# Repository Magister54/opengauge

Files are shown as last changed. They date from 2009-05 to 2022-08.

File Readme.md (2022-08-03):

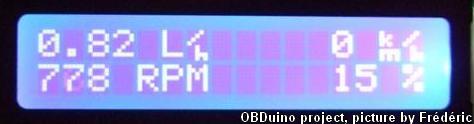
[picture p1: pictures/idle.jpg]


# Introduction #

The OBDuino is an in-car real-time display of various information, like speed, RPM, instant fuel consumption or average trip fuel consumption as well as others PIDs supported by the car.

# Details #

The name OBDuino comes from OBD which means [On Board Diagnostics](http://en.wikipedia.org/wiki/On_Board_Diagnostics) and from the development board which is an [Arduino](http://arduino.cc) (or a clone).
_Technical info_: It is based on an Atmel AVR ATMEGA168P chip that contains 16K of flash, 1K of RAM and 512bytes of EEPROM, an LCD display, 3 buttons, a few $ of electronics components.

The OBDuino connects to the car on its OBD-II plug which is, in general, under the dash. A lot of signals are on this plug as well as battery voltage and ground. Using a standard OBD-II to DB9F cable brings us what we need.

The [interface](OBDuinoInterface.md) to the car is made with either a Freescale MC33290 for ISO only, a Microchip 2515 for CAN only, or an ELM327 (a third-party pre-programmed PIC) that talks PWM/VPW/ISO/CAN but it is more expensive and can require more hardware work if you want to use all protocols.

OBDuino can display 4 informations at a time, and there is virtual screens to have access to others PIDs. By default there is 3 screens available so it makes 12 PIDs available quickly.

# Main Hardware #

The Arduino or a clone can be purchased assembled, in a kit, or you can even etch it yourself. Take the flavour you want for serial or USB depending on your PC/laptop configuration (you need the port to program the chip). All the clone should work the same, except the very small one that use 3.3V and 8MHz and even there, it should work too with some adaptation. It costs about $15-$33 depending of your choice.

To play with, you can start with a "big" board like an Arduino Diecimila or a Freeduino SB, and to integrate in the car you can use a Boarduino or an iDuino by after.

The LCD screen used is a 2 rows x 16 characters using a standard HD44780 or compatible chipset, they can be found on eBay for $4, and they exist in almost every colours as well as STN, FSTN and even OLED (although more expensive).

The 3 buttons are momentary push button switches, take the one you want. You also need a 220 ohms resistor and a PNP 2N3906 transistor or equivalent like an NTE159 to drive the LCD brightness, as it can take up to 200mA on some LCD and the pin used to drive brightness is limited to about 20mA. radio-shack has them, or online electronic parts seller like Digikey or Mouser.

With this you have the main hardware and now need the car interface.

# Interfaces #

The code can use multiple interface (although one at a time), you will need to make the interface specific for your car, see [Interface](OBDuinoInterface.md). If your car is sold in north-america and is a 2008+ it uses CAN so you can built the interface using Microchip MCP2515 and MCP2551.

Interface connect to the Arduino on a few pins, depending on your choice, the LCD will be connected differently, see [Diagram](OBDuinoDiagram.md).

# Menu Configuration #

## Role of the three buttons ##

| | realtime display  | menu display |
|:---|:---|:---|
| LEFT |  rotate screen | decrease, select NO |
| MIDDLE | go into menu | apply and go to next item |
| RIGHT  | rotate brightness | increase, select YES |
| MIDDLE+RIGHT | trip reset |  |
| MIDDLE+LEFT | tank trip reset |  |

### Reset trip data (NO/YES) ###
When you press middle and right button, a screen appear: Select if you want to reset the data and press middle button to ack.

### Reset tank data (NO/YES) ###
When you press middle and left button, a screen appear: Select if you want to reset the data and press middle button to ack.

## Configuration menu (accessed by middle button) ##

### LCD Contrast (0-100) ###
Set the LCD contrast from 0 to 100 in step 10

### Use Metric units (NO/YES) ###
NO=rods and hogshead, YES=SI

### Fuel/hour speed (0-255) ###
Speed from which the display go from L/100 or MPG, to L/h or GPH

### Tank size (n.m) ###
Size of your tank in litres or gallon

### Volume Efficiency (0-100%) (MAP only) ###
For vehicles with a MAP only we have to emulate the MAF.
This percentage will needs adjustment after you have checked manually a few tank to approximate better the fuel consumption.

### Engine Displacement (0.0-10.0) (MAP only) ###
For vehicles with a MAP only we have to emulate the MAF.
This is the size of the engine, e.g. 2.0 for a 2Liter one.

### Configure PIDs (NO/YES) ###
Choose if you want to configure the PIDs in the various screen.

### Scr 'n' Corner 'm' (0x00-0xFF) ###
(if you have selected YES at the previous item)
Select the PID you want to be displayed on screen 'n' in the corner 'm'.
A good list of PIDs is on Wikipedia [here](http://en.wikipedia.org/wiki/OBD-II_PIDs)
Some specials PIDs you can access (either by decreasing below 0 or by going far up):
  * 0xF0 - no display, meaning this corner will be blank, can be useful if another PID result is more than 8 characters
  * 0xF1 - Instant fuel consumption
  * 0xF2 - Average fuel consumption of the tank (since last tank reset)
  * 0xF3 - Fuel used in the current tank
  * 0xF4 - Distance done on the current tank
  * 0xF5 - Remaining distance that can be done on the current tank
  * 0xF6 - Average fuel consumption of the trip (since last trip reset)
  * 0xF7 - Fuel used for the current trip
  * 0xF8 - Distance of the current trip
  * 0xF9 - Battery voltage
  * 0xFA - CAN status, for CAN protocol only, display TX and RX errors

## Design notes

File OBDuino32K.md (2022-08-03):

# **WHY?** What does it do? #
This instrument will provide real time data of your car's condition and its fuel efficiency.  This directly translates to saving money! How?
The number one cause of low mileage, and the number one means of increasing your mileage are controled by just your right foot.  By providing real time feedback of your driving habits this device will provide hard data and motivation to learn to handle your vehicle in an eco-friendly manner.
With this tool, and your improved driving techniques, some have said these type of devices can pay for themselves in a month or two.

# What does it cost? #
Time and a little money.
Here is a sample list of parts, cost, and possible places to obtain them

|Part|Cost|Buy|
|:---|:---|:--|
|Arduino|$17 - $30 | [Freeduino via SB](http://www.solarbotics.com/products/28920/), [iDuino via FL](http://store.fundamentallogic.com/ecom/index.php?main_page=product_info&cPath=2&products_id=10)|
|HD44780 16X2 LCD Display|$8-$15|[FL](http://store.fundamentallogic.com/ecom/index.php?main_page=index&cPath=4_23), [ebay](http://shop.ebay.ca/i.html?_nkw=HD44780+16x2&_sacat=0&_trksid=p3286.m270.l1313&_odkw=HD44780&_osacat=0)|
|Transistors (2N3906 or NTE159)|nickles|[FL](http://store.fundamentallogic.com/ecom/index.php?main_page=index&cPath=4_5)|
|Three small push buttons|dimes|[FL](http://store.fundamentallogic.com/ecom/index.php?main_page=product_info&cPath=4_18&products_id=35) |
|220ohm & 510ohm resistor|pennies|[ebay](http://shop.ebay.ca/i.html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)|
|Interface Hardware|$5-$30|See Note 1 Below|
|DB9 (Serial) Male Connector|$1|ebay, see Note 2 Below|
|OBD2 Port Connector |$5|[ebay](http://shop.ebay.ca/i.html?_nkw=OBD2+Plug&_sacat=0&_trksid=p3286.m270.l1313&_odkw=j1962&_osacat=0)|
|Protoboard|$1 - $5|See Note 3 Below|
|Total:|$38 - $87|Searching can Save!|

Note 1, Interface hardware:
The ELM, an extra 33 dollar chip, acts as an interpreter between the OBDuino32K and the car, so that the device can, without additional programming, support ALL 1996 and later cars.  If the extra 33 dollars doesn't stop you, also consider that you will need to build additional hardware after the elm chip according to their documentation. See page 56 of their [data sheet](http://www.elmelectronics.com/DSheets/ELM327DS.pdf).

ISO9141-2 and ISO14230-4 (KWP2000) protocols are used commonly for imported cars, such as Toyota and Honda.  This is the most tested interface and accomplishes this with the use of the Freescale MC33290.  Available from [Future Electronics](http://www.futureelectronics.com/en/Search.aspx?dsNav=Ntk:PlainTextSearch|MC33290|3|,Ny:True,Nea:True), [Mouser](http://ca.mouser.com/Search/Refine.aspx?Keyword=mc33290), or [Digi-Key](http://search.digikey.com/scripts/DkSearch/dksus.dll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).

CAN Protocol is still being finalized and has not been integrated into the code base.  This is used on most newer cars (2008+).  For now, the ELM Chip is the way to go.  While progress is being made, no date is available.

Note 2, Cable Connection:
You will be building a cable that goes from the Car (OBD2 Connection) To your device.  While the Diagrams describe how to use a serial connector for the opposite end, others using just the ISO protocol have found success just using a phone cable.  This limits you to 4 wires, which means you cable will limit your device to only using ISO protocol, which in most cases is fine.

Note 3, Protoboard:
While you will use this as a base for the cable connection for your cable and possibly your MC33290 chip or other supporting hardware, some have chosen to build this device completely on one board.  This means buying an [arduino kit](http://store.fundamentallogic.com/ecom/index.php?main_page=product_info&cPath=4_28&products_id=482) without a base.  Although it means a little more planning on your part, it results in a much smaller device and will save you a few dollars at the same time!  (The kit referenced contains almost everything.  But it is missing a 5 volt regulator)

## What tools and skills will I need to build this? ##
If you have ever soldered or tinkered with electronic projects before, you can most likely build this with careful attention, and minimal bodily harm.
Collect these tools on a nice workspace:
  1. Soldering Iron
  1. Wire, Wire strippers
  1. Pliers
  1. Optionally, a helping hand tool (to help soldering that tiny MC33290 chip)

A Note about cases and construction material:
The project box to enclose your project is up to you.  Some fun choices have been an underarm deodorant container, or even a mini-rice krispy box, or a less fun plastic box.  The size and style are up to you, but keep in mind the temperature of the hot sun on your dash.  The sun _WILL_ re-melt hot glue.  While it might be quick to use to keep things in order, once things are finalized for your design it's best to use real glue or epoxy.

## What protocol does my car use? ##
While no comprehensive database with a fancy search exists, a good start is to take a look at [this chart](http://www.etools.org/files/public/generic-protocols-02-17-03.htm) to see if your vehicle is listed. Or [Here](http://www.blafusel.de/obd/obd2_scanned.php) or [here](http://www.myscantool.com/vehicles.html)
If you can not confidently find the protocol of your car there, please check the [FAQ](http://code.google.com/p/opengauge/wiki/FAQ) for more details.

# Great, I Confirmed the Protocol and Received the parts, Let's Build! #
Congratulations, Lets go to the building page:
  * [Here](http://code.google.com/p/opengauge/wiki/OBDuinoDiagram)
  * [or Here?](http://code.google.com/p/opengauge/wiki/OBDuinoInterface)

# Oh no! it doesn't work for me! #
Please check out the [FAQ](http://code.google.com/p/opengauge/wiki/FAQ) section.  If you are no further ahead, check if your answer is available on the forums at ecomodder.com.

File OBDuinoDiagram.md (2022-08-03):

# Some pictures of the main hardware #

A clone board called the freeduino, some headers were missing when I took pictures:

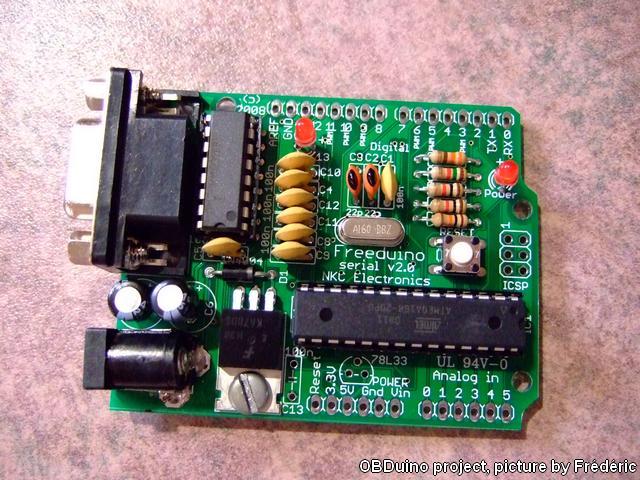
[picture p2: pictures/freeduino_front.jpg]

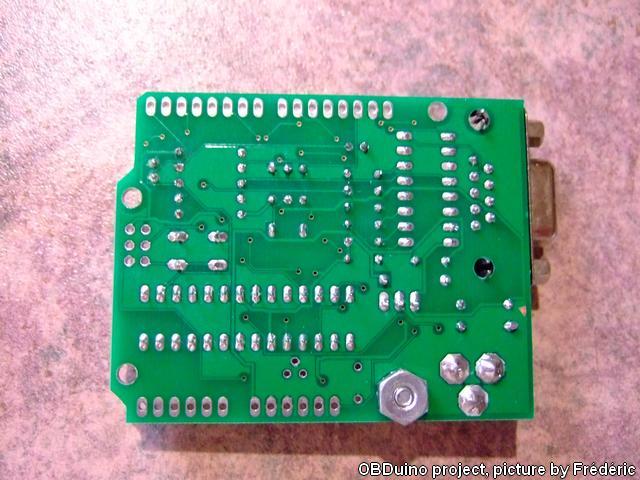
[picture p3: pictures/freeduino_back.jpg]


The LCD screen with its wires attached, note the transistor and the resistor, covered by (not yet heated) shrink tube, on the right side:

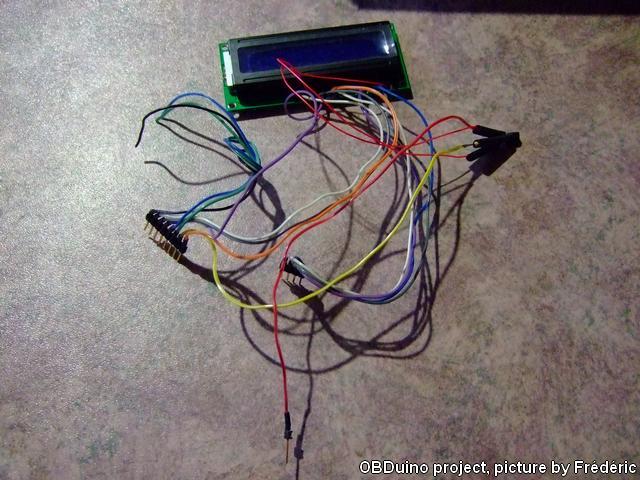
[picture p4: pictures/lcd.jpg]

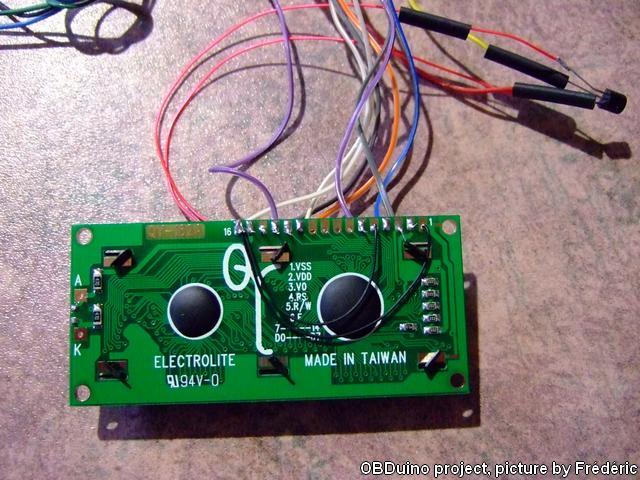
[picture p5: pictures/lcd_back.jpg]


Example of the Freeduino and LCD attached:

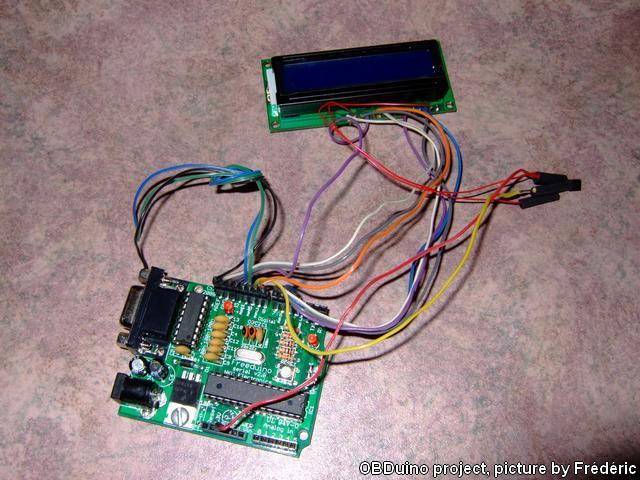
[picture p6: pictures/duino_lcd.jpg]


# ISO Diagram #

Here's the proposed diagram of the [Arduino](http://arduino.cc) board, the LCD screen, and the [ISO interface](OBDuinoInterface.md).

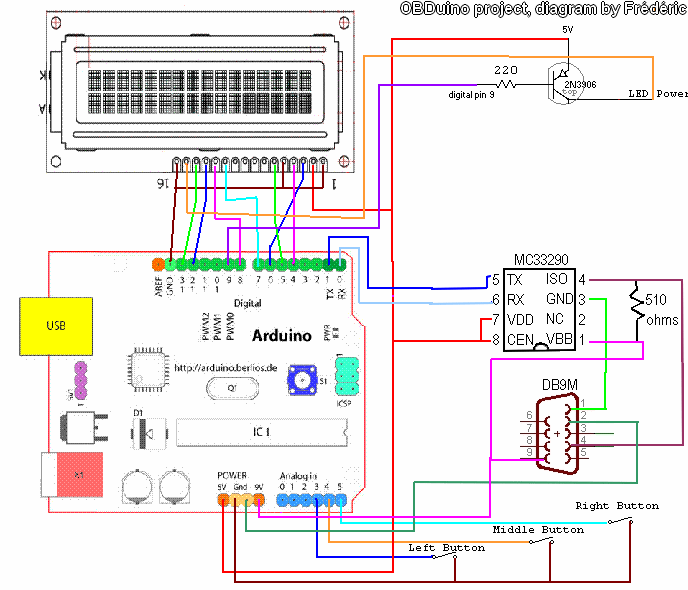
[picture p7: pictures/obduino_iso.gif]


## Hardware for ISO ##

You need:
  1. a duino clone board, serial or USB, your choice
  1. an HD44780 compatible LCD screen 2x16
  1. a transistor 2N3906 or NTE159
  1. three small push buttons
  1. a 220 ohms resistor
  1. a Freescale MC33290 ic
  1. a 510 ohms resistor
  1. a DB9 male

Freeduino, LCD, ISO interface:

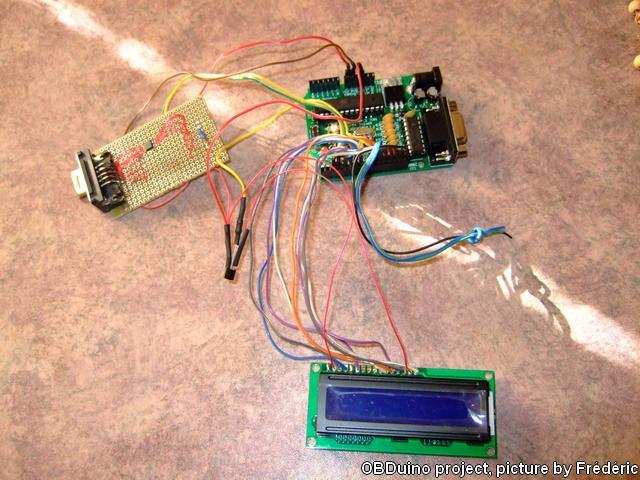
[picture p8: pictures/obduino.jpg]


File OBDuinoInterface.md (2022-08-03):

# Introduction #

You cannot directly connect pins from the OBD-II plug to the Arduino board. You need a small interface that convert the signal.

Whatever the interface needed, you also need a cable that will bring you the signals from the OBD-II plug to your OBDuino.

For all cases:
The Arduino is powered by the 12V line coming from the cable too so you need to bring some wires from the DB9M to the Arduino like this:
```
Arduino 12V input ------------------ DB9M pin 9 (12V Battery)
Arduino GND input ------------------ DB9M pin 2 (Chassis Ground)
```
**Some cars have only one ground so you may have to use DB9M pin 1 instead of pin 2 to power the board or just solder pin 1 and 2 together**

# Cable #

To keep compatibility with already existing cable, the OBDuino Interface pinout for the OBD-II to DB9F cable is wired like this:

```
DB9F			OBD-II
1---------------5  (Signal ground)
2---------------4  (Chassis ground)
3---------------6  (CAN High)
4---------------7  (ISO K line)
5---------------14 (CAN Low)
6---------------10 (J1850 bus-)
7---------------2  (J1850 bus+)
8---------------15 (ISO L Line)
9---------------16 (Battery)
```
**Do not plug it into a PC!!! This goes to an interface only!!!**

Example of my home made cable:

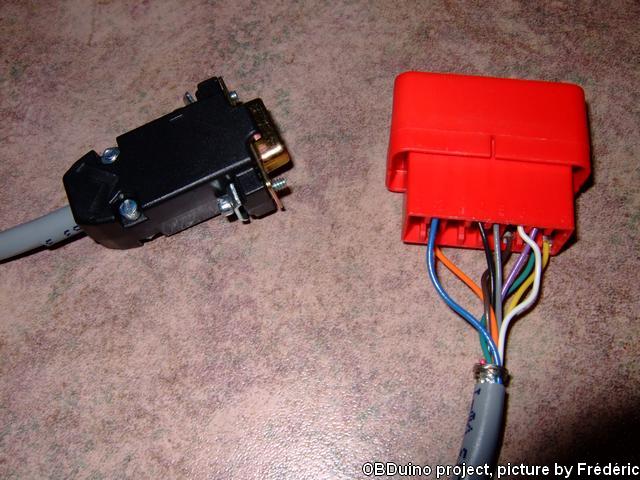
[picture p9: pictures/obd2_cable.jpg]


A nice place to get OBD-II plugs and already made cable is [Senso](http://www.sensolutions.com/products/browse-products/) which are located in Canada.

You can also find plugs at http://www.carplugs.com/ or http://www.obd2allinone.com/sc/details.asp?item=obd2cable and others.

## CAN only cable ##

A proposed CAN only cable, smaller and thinner, can be wired like this:
```
RJ-10     		OBD-II
1 (black) ------5  (Signal ground)
2 (red)---------14 (CAN Low)
3 (green)-------6  (CAN High)
4 (yellow)------16 (Battery)
```
source http://www.controllerareanetwork.com/CANcables.htm

# Interfaces #

## Interface for ISO ##

This interface converts the ISO signals for the Arduino inputs.
It consists of a small IC ([Freescale MCZ33290EF](http://www.freescale.com/webapp/sps/site/prod_summary.jsp?code=MC33290)), a 510 ohms resistor, a DB9M that will be plugged with the cable mentioned above, and few wires that connect to the Arduino board.

The MC33290 is a small chip, you can solder some wires on it for better handling.
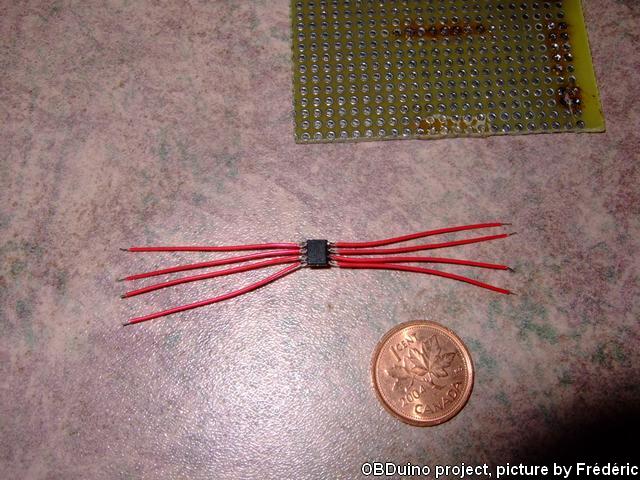
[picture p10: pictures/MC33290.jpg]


Schematic is like this:
```
                             MC33290
                            +-------+
Arduino pin 1 -------------5|TX  ISO|4-----------------+------- DB9M pin 4 (ISO K Line)
                            |       |                  |
Arduino pin 0 -------------6|RX  GND|3--DB9M pin 1     / between MC pin 4 and pin 1
                            |       |                  \ goes a 510 ohms resistor
Arduino 5V pin output -----7|VDD  NC|2--               /
                            |       |                  |
Arduino 5V pin output -----8|CEN VBB|1-----------------+------- DB9M pin 9 (12V Battery)
                            +-------+
```

Interface front:

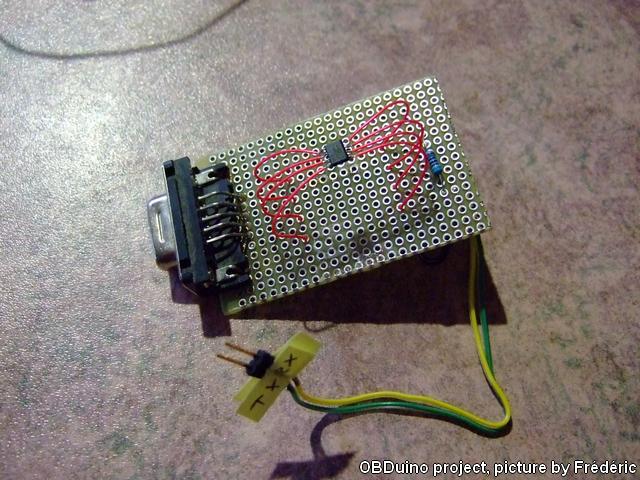
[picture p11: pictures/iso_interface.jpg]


Interface back:

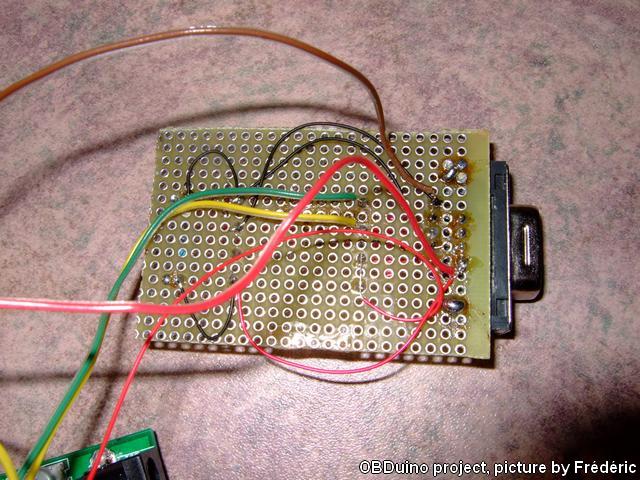
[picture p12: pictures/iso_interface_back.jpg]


## Interface with ELM ##

CAN protocol is not easy to program so as a phase 1 I am using an [http:http://www.elmelectronics.com/ ELM327] for this. This chip integrates all protocol so it could be used for ISO/VPW/PWM as well, but it's a $32+s/h chip that add to the duino and LCD, plus a few components.

Note that for PWM/VPW it should be possible to use an ELM320 or ELM323 respectively, which is cheaper than the ELM327 and would require almost no change to the code, but you would still need to do some hadware, schematics are avalaible on some web site.

Diagram of the interface (adaptation of the generic diagram found in the PDF of the ELM327):

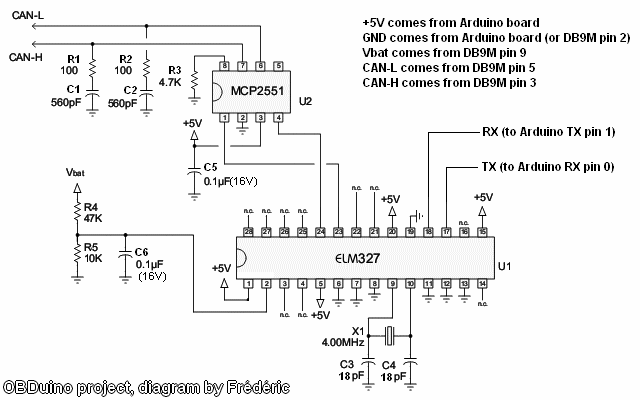
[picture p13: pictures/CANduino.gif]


On the diagram, note that CAN-L (OBD2 pin 14) go to a DB9M pin 5 and CAN-H (OBD2 pin 6) go to a DB9M pin 3. +5V comes from the Arduino board.

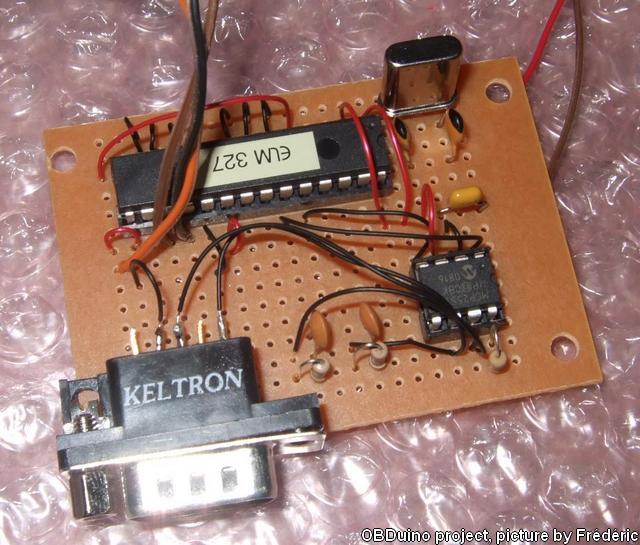
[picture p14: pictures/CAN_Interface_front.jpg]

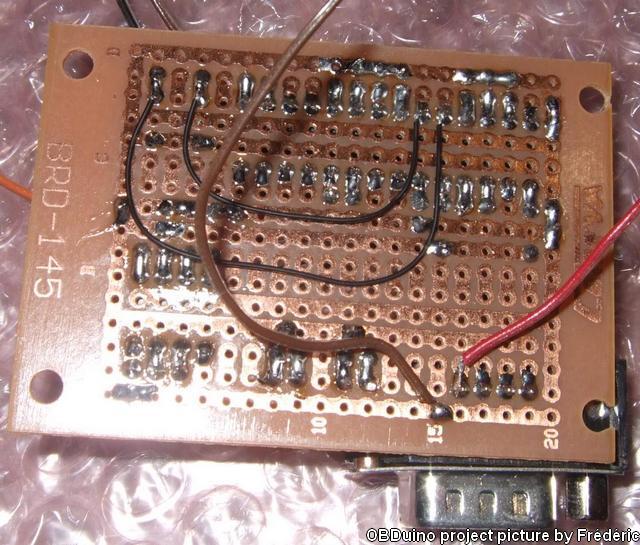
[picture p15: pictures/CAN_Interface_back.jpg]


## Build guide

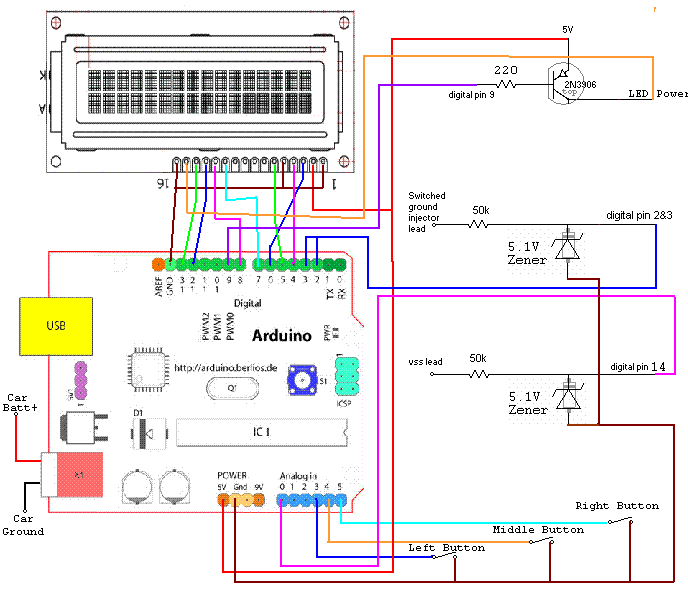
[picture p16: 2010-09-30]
mpguino/wiring.GIF

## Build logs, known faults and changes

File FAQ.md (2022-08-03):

# Q1: What protocol does my vehicle support #
A good start is to take a look at [this chart](http://www.etools.org/files/public/generic-protocols-02-17-03.htm) to see if your vehicle is listed. Or [Here](http://www.blafusel.de/obd/obd2_scanned.php) or [here](http://www.myscantool.com/vehicles.html)

However, the best way to determine the protocol your vehicle supports is to look at the available pins on the OBD II port of your car.  This is usually located under the steering wheel.

http://www.onboarddiagnostics.com/page03.htm lists the five different protocols and their pin outs as follows:
  * PWM (J1850)

  * VPW (J1850)

  * ISO (9141-2)  and  KWP2000

  * CAN (ISO 15765)


# Q2: I tried running OBDuino, but all I get is ISO 9141 Init... Failed. What do I do? #
The problem could be in either: Protocol or Wiring.
  1. Protocol
    * Using Question 1, verify that your car is indeed the ISO-9141 protocol.
    * The way each company implements the protocol may differ slightly and the software might not be prepared to handle it.  For example it may not wait long enough for a reply, or it may be getting an unexpected reply it doesn't know how to handle.
  1. Wiring
    * Double check all your connections thoroughly.
    * Try re-soldering each pin to ensure good connections.

# Q3: I have a great idea for this project that I think others would enjoy having, how do I request it, or have it added? #
The best place currently to interact with this project is on the forums at ecomodder.com located [here](http://ecomodder.com/forum/opengauge-mpguino-fe-computer.html).  Look for the thread called OBD mpguino gauge.

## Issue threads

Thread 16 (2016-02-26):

Diesel engine adaptation

aestradarespeto, 2016-02-26:
I have tested in deep obduino32k in my KIA Ceed 2.0 CRDI 140hp diesel car. The only way I have done to get real gas oil waste in my car is about using two moderate PIDs in waste equation, One is FUEL_RAIL_DIESEL and the other LOAD_VALUE, both of them must be ponderated at a percent of its values according with the values obtained in respect to the the full range of values available for my engine. I have extensively modified original obduino32k to match my hardware options (buzzer), alert options (coolant temperature), and visual options (more screens). I want to modify more this magnific program to match other needs I have. I want to make it to communicate also (I mean with ECU and the second device at a time) with an arduino that emulates the behaviour of the ECU, this second arduino is located in the engine zone and is intended to collect some parameter of the engine that are not showed with PIDs by the car ECU, thru the using of attached sensors. This sensors are: A coolant level sensor, an electro cooling  fan rpm sensor, a temperature probe sensor in external coolant circuit, and a temperature sensor for oil. I have trid to enclose the up to date obduino32k modified available, but there is some error in that,so I can send by request to aestradarespeto@gmail.com.

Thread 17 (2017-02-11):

Hangs when loosing serial communication

aestradarespeto, 2017-02-11:
I use obduino32k in my Kia CEED 2.0 CRDI diesel car. I am using a HC-05 master bluetooth adapter attached to my arduino in order to communicate with my ELM 2.7 bluetooth device. The communication between devices thru bluetooth (BT) is fine, and the project works flawlessly. But when the BT communication is lost by any cause, i.e. ELM removal, the system hangs. When hangs, it not reinitiates or respond to buttons, it freezes in the last active sceen. I have checked obduino32k code in order to modify some code line  to perform a elm_init() void execution that could solve the freeze, but I am not so skilled in programming to do so. Any help will be welcome.

Magister54, 2017-02-14:
It's been years I looked at this code, the serial read iso_read_byte() has a timeout, it should return false then iso_read_data() should return something different than a predefined value then it should display "ERROR".
At least with a real serial port, with an HC-05 I don't know what could happen :-/

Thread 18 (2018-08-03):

fix MIL polling

adrien-lessard, 2018-08-03:
obduino.pde, line 1397:

`for(i=0;i<nb/3;i++)  // each received packet contain 3 codes`

If nb is 1 or 2, `nb/3` will be evaluated to 0 and the code will not read the error codes.

Quick fix is to change the line for:

`for(i=0;i<(nb+2)/3;i++)  // each received packet contain 3 codes`

to receive the right number of error codes

The fix has been tested on a STM32 discovery board and an Toyota Echo 2005. You saved me the trouble of going to the garage, thanks!

Magister54, 2018-10-01:
It was fixed with
for (j = 0; j < (nb-1)/3 + 1; j++)
in the 32K version

Closed 2018-10-01.

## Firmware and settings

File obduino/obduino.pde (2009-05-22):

//#define DEBUG

// comment to use MC33290 ISO K line chip
// uncomment to use ELM327
//#define ELM

/* OBDuino

 Copyright (C) 2008-2009

 Main coding/ISO/ELM: Frédéric (aka Magister on ecomodder.com)
 LCD part: Dave (aka dcb on ecomodder.com), optimized by Frédéric
 Fixes and Features: 
  Russ: Added serial_rx_off() and serial_rx_on() functions to disable and enable serial receiver
        Modified iso_write_byte() to disable serial receiver while sending to avoid echos in buffer
        Modified iso_write_byte() to include intrabyte delay
        Modified iso_write_data() to remove intrabyte delay (now included in iso_write_byte())
        Modified iso_read_data() to return only data, not PID + data
        Modified iso_read_data() to insure minimum 55 ms delay between requests
        Modified pid_reslen table to correct some lengths-others appear incorrect but aren't supported
          by my car, so I can't verify.  Specifically, some lengths are 8, when max data size in 
          iso 9141 packet is 7.
  Mike: Added Tracking of Fuel wasted while idling, total for tank displayed when engine shut off.
        Modified iso_read_byte() to return 0 if no respose is received [for when ECU shuts off quicker
           then the engine so the progam will now know when engine is off and can save parameters]
        Backlight will turn off when engine is not running.

Still need to:
          Modify iso_init to allow re-init without resetting arduino.
          Fix code to retrieve stored trouble codes.
 
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
 You should have received a copy of the GNU General Public License along with
 this program; if not, write to the Free Software Foundation, Inc.,
 59 Temple Place, Suite 330, Boston, MA 02111-1307, USA
 */

#undef int
#include <stdio.h>
#include <avr/eeprom.h>
#include <avr/pgmspace.h>

// LCD Pins same as mpguino
#define DIPin 4 // register select RS
#define DB4Pin 7
#define DB5Pin 8
#define DB6Pin 12
#define DB7Pin 13
#define ContrastPin 6
#define EnablePin 5
#define BrightnessPin 9

// LCD prototypes
void lcd_gotoXY(byte x, byte y);
void lcd_print(char *string);
void lcd_print_P(char *string);  // to work with string in flash and PSTR()
void lcd_cls_print_P(char *string);  // clear screen and display string
void lcd_cls();
void lcd_init();
void lcd_tickleEnable();
void lcd_commandWriteSet();
void lcd_commandWrite(byte value);
void lcd_dataWrite(byte value);
void lcd_pushNibble(byte value);

// Memory prototypes
void params_load(void);
void params_save(void);

// Others prototypes
byte menu_select_yes_no(byte p);
void long_to_dec_str(long value, char *decs, byte prec);
int memoryTest(void);
void test_buttons(void);

#define BUTTON_DELAY  250
// use analog pins as digital pins for buttons
#define lbuttonPin 17 // Left Button, on analog 3
#define mbuttonPin 18 // Middle Button, on analog 4
#define rbuttonPin 19 // Right Button, on analog 5

#define lbuttonBit 8 //  pin17 is a bitmask 8 on port C
#define mbuttonBit 16 // pin18 is a bitmask 16 on port C
#define rbuttonBit 32 // pin19 is a bitmask 32 on port C
#define buttonsUp  lbuttonBit + mbuttonBit + rbuttonBit  // start with the buttons in the right state
byte buttonState = buttonsUp;

byte brightness[]={
  40,80,120,160}; // right button cycles through these brightness settings
#define brightnessLength 4 //array size
byte brightnessIdx=1;

/* PID stuff */

unsigned long  pid01to20_support;  // this one always initialized at setup()
unsigned long  pid21to40_support=0;
unsigned long  pid41to60_support=0;
#define PID_SUPPORT00 0x00
#define MIL_CODE      0x01
#define FREEZE_DTC    0x02
#define FUEL_STATUS   0x03
#define LOAD_VALUE    0x04
#define COOLANT_TEMP  0x05
#define STFT_BANK1     0x06
#define LTFT_BANK1     0x07
#define STFT_BANK2     0x08
#define LTFT_BANK2     0x09
#define FUEL_PRESSURE 0x0A
#define MAN_PRESSURE  0x0B
#define ENGINE_RPM    0x0C
#define VEHICLE_SPEED 0x0D
#define TIMING_ADV    0x0E
#define INT_AIR_TEMP  0x0F
#define MAF_AIR_FLOW  0x10
#define THROTTLE_POS  0x11
#define SEC_AIR_STAT  0x12
#define OXY_SENSORS1  0x13
#define B1S1_O2_V     0x14
#define B1S2_O2_V     0x15
#define B1S3_O2_V     0x16
#define B1S4_O2_V     0x17
#define B2S1_O2_V     0x18
#define B2S2_O2_V     0x19
#define B2S3_O2_V     0x1A
#define B2S4_O2_V     0x1B
#define OBD_STD       0x1C
#define OXY_SENSORS2  0x1D
#define AUX_INPUT     0x1E
#define RUNTIME_START 0x1F
#define PID_SUPPORT20 0x20
#define DIST_MIL_ON   0x21
#define FUEL_RAIL_P   0x22
#define FUEL_RAIL_DIESEL 0x23
#define O2S1_WR_V     0x24
#define O2S2_WR_V     0x25
#define O2S3_WR_V     0x26
#define O2S4_WR_V     0x27
#define O2S5_WR_V     0x28
#define O2S6_WR_V     0x29
#define O2S7_WR_V     0x2A
#define O2S8_WR_V     0x2B
#define EGR           0x2C
#define EGR_ERROR     0x2D
#define EVAP_PURGE    0x2E
#define FUEL_LEVEL    0x2F
#define WARM_UPS      0x30
#define DIST_MIL_CLR  0x31
#define EVAP_PRESSURE 0x32
#define BARO_PRESSURE 0x33
#define O2S1_WR_C     0x34
#define O2S2_WR_C     0x35
#define O2S3_WR_C     0x36
#define O2S4_WR_C     0x37
#define O2S5_WR_C     0x38
#define O2S6_WR_C     0x39
#define O2S7_WR_C     0x3A
#define O2S8_WR_C     0x3B
#define CAT_TEMP_B1S1 0x3C
#define CAT_TEMP_B2S1 0x3D
#define CAT_TEMP_B1S2 0x3E
#define CAT_TEMP_B2S2 0x3F
#define PID_SUPPORT40 0x40
#define MONITOR_STAT  0x41
#define CTRL_MOD_V    0x42
#define ABS_LOAD_VAL  0x43
#define CMD_EQUIV_R   0x44
#define REL_THR_POS   0x45
#define AMBIENT_TEMP  0x46
#define ABS_THR_POS_B 0x47
#define ABS_THR_POS_C 0x48
#define ACCEL_PEDAL_D 0x49
#define ACCEL_PEDAL_E 0x4A
#define ACCEL_PEDAL_F 0x4B
#define CMD_THR_ACTU  0x4C
#define TIME_MIL_ON   0x4D
#define TIME_MIL_CLR  0x4E

#define LAST_PID      0x4E  // same as the last one defined above

/* our internal fake PIDs */
#define NO_DISPLAY    0xF0
#define FUEL_CONS     0xF1    // instant cons
#define TANK_CONS     0xF2    // average cons of tank
#define TANK_FUEL     0xF3    // fuel used in tank
#define TANK_DIST     0xF4    // distance for tank
#define REMAIN_DIST   0xF5    // remaining distance of tank
#define TRIP_CONS     0xF6    // average cons of trip
#define TRIP_FUEL     0xF7    // fuel used in trip
#define TRIP_DIST     0xF8    // distance of trip
#define BATT_VOLTAGE  0xF9
#define OUTING_CONS  0xFA
#define OUTING_FUEL  0xFB
#define OUTING_DIST  0xFC
//#define ECO_VISUAL    0XFC    // Visually dispay relative economy with *'s (too big, not tested)
#define CAN_STATUS    0xFD
#define PID_SEC       0xFE
#ifdef DEBUG
#define FREE_MEM      0xFF
#endif

// returned length of the PID response.
// constants so put in flash
prog_uchar pid_reslen[] PROGMEM=
{
  // pid 0x00 to 0x1F
  4,4,2,2,1,1,1,1,1,1,1,1,2,1,1,1,
  2,1,1,1,2,2,2,2,2,2,2,2,1,1,1,4,

  // pid 0x20 to 0x3F
  4,2,2,2,4,4,4,4,4,4,4,4,1,1,1,1,
  1,2,2,1,4,4,4,4,4,4,4,4,2,2,2,2,

  // pid 0x40 to 0x4E
  4,8,2,2,2,1,1,1,1,1,1,1,1,2,2
};

// for the 4 display corners
#define TOPLEFT  0
#define TOPRIGHT 1
#define BOTTOMLEFT  2
#define BOTTOMRIGHT 3
#define NBCORNER 4   // with a 16x4 display you could use 8 'corners'
#define NBSCREEN  3  // 12 PIDs should be enough for everyone
byte active_screen=0;  // 0,1,2,... selected by left button
prog_char blkstr[] PROGMEM="        "; // 8 spaces, used to clear part of screen
prog_char pctd[] PROGMEM="- %d + "; // used in a couple of place
prog_char pctdpctpct[] PROGMEM="- %d%% + "; // used in a couple of place
prog_char pctspcts[] PROGMEM="%s %s"; // used in a couple of place
prog_char pctldpcts[] PROGMEM="%ld %s"; // used in a couple of place
prog_char select_no[]  PROGMEM="(NO) YES"; // for config menu
prog_char select_yes[] PROGMEM="NO (YES)"; // for config menu

// to differenciate trips
#define TANK         0
#define TRIP         1
#define OUTING_TRIP 2  //Tracks your current outing 
#define NBTRIP       3

// parameters
// each trip contains fuel used and distance done
typedef struct
{
  unsigned long dist;   // in cm
  unsigned long fuel;   // in µL
  unsigned long waste;  // in µL
}
trip_t;

// each screen contains n corners
typedef struct
{
  byte corner[NBCORNER];
}
screen_t;

typedef struct
{
  byte contrast;       // we only use 0-100 value in step 20
  byte use_metric;     // 0=rods and hogshead, 1=SI
  byte per_hour_speed; // speed from which we toggle to fuel/hour (km/h or mph)
  byte fuel_adjust;    // because of variation from car to car, temperature, etc
  byte speed_adjust;   // because of variation from car to car, tire size, etc
  byte eng_dis;        // engine displacement in dL
  unsigned int  tank_size;   // tank size in dL or dgal depending of unit
  trip_t trip[NBTRIP];        // trip0=tank, trip1=a trip
  screen_t screen[NBSCREEN];  // screen
}
params_t;

// parameters default values
params_t params=
{
  40,
  1,
  20,
  100,
  100,
  16,
  450,
  {
    { 0,0 },
    { 0,0 }
  },
  {
    { { FUEL_CONS,LOAD_VALUE,TANK_CONS, OUTING_FUEL} },
    { {TRIP_CONS,TRIP_DIST,TRIP_FUEL,COOLANT_TEMP} } ,
    { {TANK_CONS,TANK_DIST,TANK_FUEL,REMAIN_DIST} }
  }
};

#define STRLEN  40

#ifdef ELM
#define NUL     '\0'
#define CR      '\r'  // carriage return = 0x0d = 13
#define PROMPT  '>'
#define DATA    1  // data with no cr/prompt
#else
/*
 * for ISO9141-2 Protocol
 */
#define K_IN    0
#define K_OUT   1
#endif

// some globals, for trip calculation and others
unsigned long old_time;
byte has_rpm=0;
long vss=0;  // speed
long maf=0;  // MAF

unsigned long getpid_time;
byte nbpid_per_second=0;

// flag used to save distance/average consumption in eeprom only if required
byte engine_started=0;
byte param_saved=0;

// the buttons interrupt
// this is the interrupt handler for button presses
ISR(PCINT1_vect)
{
#if 0
  static unsigned long last_millis = 0;
  unsigned long m = millis();

  if (m - last_millis > 20)
  { // do pushbutton stuff
    buttonState &= PINC;
  }
  //  else ignore interrupt: probably a bounce problem
  last_millis = m;
#else
  buttonState &= PINC;
#endif
}

#ifdef ELM
/* each ELM response ends with '\r' followed at the end by the prompt
 so read com port until we find a prompt */
byte elm_read(char *str, byte size)
{
  int b;
  byte i=0;

  // wait for something on com port
  while((b=serialRead())!=PROMPT && i<size)
  {
    if(/*b!=-1 &&*/ b>=' ')
      str[i++]=b;
  }

  if(i!=size)  // we got a prompt
  {
    str[i]=NUL;  // replace CR by NUL
    return PROMPT;
  }
  else
    return DATA;
}

// buf must be ASCIIZ
void elm_write(char *str)
{
  while(*str!=NUL)
    serialWrite(*str++);
}

// check header byte
byte elm_check_response(const char *cmd, char *str)
{
  // cmd is something like "010D"
  // str should be "41 0D blabla"
  if(cmd[0]+4 != str[0]
    || cmd[1]!=str[1]
    || cmd[2]!=str[3]
    || cmd[3]!=str[4])
    return 1;

  return 0;  // no error
}

byte elm_compact_response(byte *buf, char *str)
{
  byte i=0;

  // start at 6 which is the first hex byte after header
  // ex: "41 0C 1A F8"
  // return buf: 0x1AF8

  str+=6;
  while(*str!=NUL)
    buf[i++]=strtoul(str, &str, 16);  // 16 = hex

  return i;
}

// write simple string to ELM and return read result
// cmd is a PSTR !!
byte elm_command(char *str, char *cmd)
{
  sprintf_P(str, cmd);
  elm_write(str);
  return elm_read(str, STRLEN);
}

void elm_init()
{
  char str[STRLEN];

  beginSerial(9600);
  serialFlush();

#ifndef DEBUG
  // reset, wait for something and display it
  elm_command(str, PSTR("ATWS\r"));
  lcd_gotoXY(0,1);
  if(str[0]=='A')  // we have read back the ATWS
    lcd_print(str+4);
  else
    lcd_print(str);
  lcd_print_P(PSTR(" Init"));

  // turn echo off
  elm_command(str, PSTR("ATE0\r"));

  // send 01 00 until we are connected
  do
  {
    elm_command(str, PSTR("0100\r"));
    delay(1000);
  }
  while(elm_check_response("0100", str)!=0);

  // ask protocol
  elm_command(str, PSTR("ATDPN\r"));
  // str[0] should be 'A' for automatic
  // set header to talk directly to ECU#1
  if(str[1]=='1')  // PWM
    elm_command(str, PSTR("ATSHE410F1\r"));
  else if(str[1]=='2')  // VPW
    elm_command(str, PSTR("ATSHA810F1\r"));
  else if(str[1]=='3')  // ISO 9141
    elm_command(str, PSTR("ATSH6810F1\r"));
  else if(str[1]=='6')  // CAN 11 bits
    elm_command(str, PSTR("ATSH7E0\r"));
  else if(str[1]=='7')  // CAN 29 bits
    elm_command(str, PSTR("ATSHDA10F1\r"));
#endif
}
#else

void serial_rx_on() {
//  UCSR0B |= _BV(RXEN0);  //enable UART RX
  Serial.begin(10400);		//setting enable bit didn't work, so do beginSerial
}

void serial_rx_off() {
  UCSR0B &= ~(_BV(RXEN0));  //disable UART RX
}

void serial_tx_off() {

   UCSR0B &= ~(_BV(TXEN0));  //disable UART TX
   delay(20);                 //allow time for buffers to flush
}


int iso_read_byte()
{
  int b;
  byte t=0;
  while(t!=125  && (b=serialRead())==-1) {
    delay(1);
    t++;
  }
  if (t>=125) {
    b = 0;
  }
  return b;
}

void iso_write_byte(byte b)
{
  serial_rx_off();
  serialWrite(b);
  delay(10);		// ISO requires 5-20 ms delay between bytes.
  serial_rx_on();
}

// inspired by SternOBDII\code\checksum.c
byte iso_checksum(byte *data, byte len)
{
  byte i;
  byte crc;

  crc=0;
  for(i=0; i<len; i++)
    crc=crc+data[i];

  return crc;
}

// inspired by SternOBDII\code\iso.c
byte iso_write_data(byte *data, byte len)
{
  byte i, n;
  byte buf[20];

  // ISO header
  buf[0]=0x68;
  buf[1]=0x6A;		// 0x68 0x6A is an OBD-II request
  buf[2]=0xF1;		// our requester’s address (off-board tool)
  // append message
  for(i=0; i<len; i++)
    buf[i+3]=data[i];

  // calculate checksum
  i+=3;
  buf[i]=iso_checksum(buf, i);

  // send char one by one
  n=i+1;
  for(i=0; i<n; i++)
  {
    iso_write_byte(buf[i]);
  }

  return 0;
}

// read n byte of data (+ header + cmd and crc)
// return the result only in data
byte iso_read_data(byte *data, byte len)
{
  byte i;
  byte buf[20];

  // header 3 bytes: [80+datalen] [destination=f1] [source=01]
  // data 1+1+len bytes: [40+cmd0] [cmd1] [result0]
  // checksum 1 bytes: [sum(header)+sum(data)]

    for(i=0; i<3+1+1+1+len; i++)
    buf[i]=iso_read_byte();

  // test, skip header comparison
  // ignore failure for the moment (0x7f)
  // ignore crc for the moment

  // we send only one command, so result start at buf[4] Actually, result starts at buf[5], buf[4] is pid requested...
  memcpy(data, buf+5, len);

  delay(55);    //guarantee 55 ms pause between requests

  return len;
}
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
void loop()                     // run over and over again
{
  char str[STRLEN];

  // test if engine is started
  has_rpm=(get_pid(ENGINE_RPM, str)>0)?1:0;
  if(engine_started==0 && has_rpm!=0)
  {
    //Reset the current outing trip from last trip
    params.trip[OUTING_TRIP].dist=0;
    params.trip[OUTING_TRIP].fuel=0;
    params.trip[OUTING_TRIP].waste=0;
    engine_started=1;
    param_saved=0;
    analogWrite(BrightnessPin,255-brightness[brightnessIdx]);

  }

  // if engine was started but RPM is now 0
  // save param only once, by flopping param_saved
  if(has_rpm==0 && param_saved==0 && engine_started!=0)
  {
    params_save();
    param_saved=1;
    engine_started=0;
    lcd_cls_print_P(PSTR("TRIPS SAVED!"));
    //Lets Display how much fuel for the tank we wasted.
    #ifndef ELM  //Just not enough room for ELM
    lcd_gotoXY(0,1);
    char decs[16];
    long_to_dec_str((params.trip[TANK].waste/10000), decs, 2);
    lcd_print(decs);
    lcd_gotoXY(8,1);
    lcd_print_P(PSTR("L wasted"));
    #endif
    delay(2000);
    //Turn the Backlight off
    analogWrite(BrightnessPin,255);

  }

  // this read and assign vss and maf and accumulate trip data
  accu_trip();

  // display on LCD
  for(byte cur_corner=0; cur_corner<NBCORNER; cur_corner++)
    display(cur_corner, params.screen[active_screen].corner[cur_corner]);

  // test buttons
  test_buttons();
}

/*
 * Memory related functions
 */

// we have 512 bytes of EEPROM on the 168P, more than enough
void params_save(void)
{
  uint16_t crc;
  byte *p;

  // CRC will go at the end
  crc=0;
  p=(byte*)&params;
  for(byte i=0; i<sizeof(params_t); i++)
    crc+=p[i];

  // start at address 0
  eeprom_write_block((const void*)&params, (void*)0, sizeof(params_t));
  // write CRC after params struct
  eeprom_write_word((uint16_t*)sizeof(params_t), crc);
}

void params_load(void)
{
  params_t params_tmp;
  uint16_t crc, crc_calc;
  byte *p;

  // read params
  eeprom_read_block((void*)&params_tmp, (void*)0, sizeof(params_t));
  // read crc
  crc=eeprom_read_word((const uint16_t*)sizeof(params_t));

  // calculate crc from read stuff
  crc_calc=0;
  p=(byte*)&params_tmp;
  for(byte i=0; i<sizeof(params_t); i++)
    crc_calc+=p[i];

  // compare CRC
  if(crc==crc_calc)     // good, copy read params to params
    params=params_tmp;
}

#ifdef DEBUG  // how can this takes 578 bytes!!
// this function will return the number of bytes currently free in RAM
// there is about 670 bytes free in memory when OBDuino is running
extern int  __bss_end;
extern int  *__brkval;
int memoryTest(void)
{
  int free_memory;
  if((int)__brkval == 0)
    free_memory = ((int)&free_memory) - ((int)&__bss_end);
  else
    free_memory = ((int)&free_memory) - ((int)__brkval);
  return free_memory;
}
#endif

/*
 * LCD functions
 */
// x=0..16, y=0..1
void lcd_gotoXY(byte x, byte y)
{
  byte dr=0x80+x;
  if(y!=0)    // save 2 bytes compared to "if(y==1)"
    dr+=0x40;
  lcd_commandWrite(dr);
}

void lcd_print(char *string)
{
  while(*string != 0)
    lcd_dataWrite(*string++);
}

void lcd_print_P(char *string)
{
  char str[STRLEN];

  sprintf_P(str, string);
  lcd_print(str);
}

void lcd_cls_print_P(char *string)
{
  lcd_cls();
  lcd_print_P(string);
}

// do the lcd initialization voodoo
// thanks to Yoshi "SuperMID" for tips :)
void lcd_init()
{
  delay(16);                    // wait for more than 15 msec

  for(byte i=0; i<3; i++)
  {
    lcd_pushNibble(B00110000);  // send (B0011) to DB7-4
    lcd_commandWriteSet();
    delay(5);                     // wait for more than 4.1 msec or 100 usec
  }

  lcd_pushNibble(B00100000);  // send (B0010) to DB7-4 for 4bit
  lcd_commandWriteSet();
  delay(1);                     // wait for more than 100 usec
  // ready to use normal CommandWrite() function now!

  lcd_commandWrite(B00101000);   // 4-bit interface, 2 display lines, 5x8 font
  lcd_commandWrite(B00001100);   // display control on, no cursor, no blink
  lcd_commandWrite(B00000110);   // entry mode set: increment automatically, no display shift

  //creating the custom fonts (8 char max)
  // char 0 is not used
  // 1&2 is the L/100 datagram in 2 chars only
  // 3&4 is the km/h datagram in 2 chars only
  // 5 is the ° char (degree)
  // 6&7 is the mi/g char
#define NB_CHAR  7
  // set cg ram to address 0x08 (B001000) to skip the
  // first 8 rows as we do not use char 0
  lcd_commandWrite(B01001000);
  static prog_uchar chars[] PROGMEM ={
    B10000,B00000,B10000,B00010,B00111,B11111,B00010,
    B10000,B00000,B10100,B00100,B00101,B10101,B00100,
    B11001,B00000,B11000,B01000,B00111,B10101,B01000,
    B00010,B00000,B10100,B10000,B00000,B00000,B10000,
    B00100,B00000,B00000,B00100,B00000,B00100,B00111,
    B01001,B11011,B11111,B00100,B00000,B00000,B00100,
    B00001,B11011,B10101,B00111,B00000,B00100,B00101,
    B00001,B11011,B10101,B00101,B00000,B00100,B00111,
  };

  for(byte x=0;x<NB_CHAR;x++)
    for(byte y=0;y<8;y++)  // 8 rows
      lcd_dataWrite(pgm_read_byte(&chars[y*NB_CHAR+x])); //write the character data to the character generator ram

  lcd_cls();
  lcd_commandWrite(B10000000);  // set dram to zero
}

void lcd_cls()
{
  lcd_commandWrite(B00000001);  // Clear Display
  lcd_commandWrite(B00000010);  // Return Home
}

void lcd_tickleEnable()
{
  // send a pulse to enable
  digitalWrite(EnablePin,HIGH);
  delayMicroseconds(1);  // pause 1 ms according to datasheet
  digitalWrite(EnablePin,LOW);
  delayMicroseconds(1);  // pause 1 ms according to datasheet
}

void lcd_commandWriteSet()
{
  digitalWrite(EnablePin,LOW);
  delayMicroseconds(1);  // pause 1 ms according to datasheet
  digitalWrite(DIPin,0);
  lcd_tickleEnable();
}

void lcd_pushNibble(byte value)
{
  digitalWrite(DB7Pin, value & 128);
  digitalWrite(DB6Pin, value & 64);
  digitalWrite(DB5Pin, value & 32);
  digitalWrite(DB4Pin, value & 16);
}

void lcd_commandWrite(byte value)
{
  lcd_pushNibble(value);
  lcd_commandWriteSet();
  value<<=4;
  lcd_pushNibble(value);
  lcd_commandWriteSet();
  delay(5);
}

void lcd_dataWrite(byte value)
{
  digitalWrite(DIPin, HIGH);
  lcd_pushNibble(value);
  lcd_tickleEnable();
  value<<=4;
  lcd_pushNibble(value);
  lcd_tickleEnable();
  delay(5);
}
/*
void eco_visual(char *retbuf) {
  
  unsigned long fuel;
  unsigned long dist;
  long tank_cons;
  long outing_cons;
  char decs[16];
  byte stars = 4;
  fuel=params.trip[TANK].fuel;
  dist=params.trip[TANK].dist;
  tank_cons = fuel/dist;
  
  fuel=params.trip[OUTING_TRIP].fuel;
  dist=params.trip[OUTING_TRIP].dist;
  outing_cons = fuel/dist;

  if ( outing_cons < tank_cons ) { //doing good :)
    outing_cons = outing_cons*105/100;
    while(outing_cons < tank_cons) {
      outing_cons = outing_cons*110/100;
      stars++;
    }
  } else {  //doing bad
    tank_cons = tank_cons*105/100;
    while(outing_cons > tank_cons) {
      tank_cons = tank_cons*110/100;
      stars--;
    } 
  } 
  
  for(int i=0; i++; i<stars) {
    decs[i] = '*';
  }
  decs[stars] = '\0';
  sprintf_P(retbuf, pctspcts, decs);
  
}
*/

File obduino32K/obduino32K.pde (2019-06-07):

/* OBDuino32K  (Requires Atmega328 for your Arduino)

 Copyright (C) 2008-2010

 Main coding/ISO/ELM: Frederic (aka Magister on ecomodder.com)
 ISO Communication Protocol: Russ, Antony, Mike
 Features: Mike, Antony, Eimantas
 Bugs & Fixes: Antony, Fredric, Mike, Eimantas
 LCD bignum: Frederic based on mpguino code by Dave, Eimantas

Latest Changes
May 28, 2016 (v198)
 Fixed KWP2000 implementation

Jul 11th, 2011 (v197)
 Buzzer for speed limit (active)
 Buzzer for coolant temperature (every 1min)
 Key response fixes
 
Apr 06-12th, 2011 (v193-v195)
 Summary logging to separate file
 Single pid and data collection logging (see #define useSDCard section)
 Log buffering (one access to SD card takes ~170-200ms)
 Logging to SD card (base) HOWTO in forum page 68
 TANK/TRIP/OUTING trip counters
 
Apr 06th, 2011 (v192)
 Removed not used PID_Desc (saved ~1200bytes)
 Changed SI and US units selection - if disabled saves ~1300bytes
 
Apr 04th, 2011 (v190)
 ATTENTION! this update needed additional parameters saving to EEPROM, last tank data will be lost.

 ISO reinit
 Driving and idling times for each trip (could be used for average speed and other in future)
 Max speed PID for each trip (max MAF, RPM, LOAD planned)
 ISO init first delay changes: 300ms, 600ms, 1200ms, 2400ms, 4800ms, 300ms...

 BIG pid can be configured
 do_ISO_Reinit and skip_ISO_Init disabled by default
 carAlarmScreen disabled by default and allowed to disable it separetly
 Big font type could be changed without recompiling (~400bytes fonts + ~200bytes config)
  
Mar 29th, 2011 (v189)
 AutoSave after 30min while driving (disabled by default)
 Config timeout (10s by default, last changes always accepted) (~100 bytes used)
 Battery voltage PID for ISO 9141 (was only for ELM) see get_batteryvoltage() for wiring instructions
 ISO 9141 initialization code trim (128 bytes saved)
 Gallons and litres conversion changed without functions (234 bytes saved)
 calcTimeDiff modified according to http://www.arduino.cc/playground/Code/TimingRollover (200 bytes saved)
 Bug fix in get_icons() smoothed vss was wrongly compared with toggle_speed 
Mar 10th, 2011
 Add smoothing of instant cons
Nov 7th, 2010
 Added Hybrid Big Num Screen for display AVG in Bigfont, and instant in small font in the corner
Oct 28th, 2010
 Changes to make BigNum fuctions work more fluently
September 14th, 2010:
 Different currency strings for different currencies.
 PIDs caching during same calculation cycle.
 Adjusting tank used fuel and distance.
September 6th, 2010:
 If ISO_Reinit is used added modification to skip startup init. 
   ISO_Reinit is used for first and all other initalizations
 ISO delay constants (10ms and 55ms) moved to define section.
   Lower values then allowed in specification works on some cars.
 LCD bignum
August 31st, 2010:
 ISO 9141 VW MK4 compatible
 Gasoline/LPG/Diesel support - constant in define section
 DTC read & clear improvement
 DTC read enable/disable on start
 DTC read & clear rebuild tested and working
 External temperature sensor like KTY81-210 support
 Saving TRIP data in ISO reinit mode after engine is turned off
 Turning off backlight in ISO reinit mode if RPM = 0
August 30th, 2010:
 Some LCD optimizations, formula for MAP, fix check_mil (untested)
June 9th, 2009:
 ISO 9141 re-init, ECU polling, Car alarm and other tweaks by Antony
June 24, 2009:
 Added three parameters to the mix, removed unrequired RPM call,
   added off and full to backlight levels, added waste PIDs: Antony
June 25, 2009:
 Use the metric parameter for fuel price and tank size: Antony
June 27, 2009:
 Minor corrections and tweaks: Antony
July 23, 2009:
 New menuing system for parameters, and got rid of display flicker: Antony
Sept 01, 2009:
 Better handling of 14230 protocol. Tweak in clear button routine: Antony
Sept 27, 2009:
 Correct four line LCD positioning: Nickdigger (via ecomodder.com)

To-Do:
  Bugs:
    1. Fix code to retrieve stored trouble codes.
       (2010.08.22 fixed in ISO, ELM not tested):
    2. Make the Menu response less clunky
  
  Features Requested:
    1. Aero-Drag calculations?
    2. SD Card logging:
      a) PID time limitations; loging format; analizing software or xls charts;
         logging pid selection; internal pid logging; real time clock; and other improvements.
       
    3. Add another Fake PID to track max values (Speed, RPM, Tank KM's, etc...)
    4. Add a "Score" PID, to rate you for a trip (Quickness, IdleTime, Fuel Used etc as factors)
    5. Allow config for L/100 or km/l
  
  Other:
    1. Trim the Code as we are aproaching the 30.7K limit.
      a) in config always save params (~200-300 bytes expected)
    2. Add a "dirty" flag to tank data when the obduino detects that it has been
        disconnected from the car to indicate that the data may no longer be complete
    3. Config menu optimization (one universal function for all items)


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
neral Public License as published by the Free Software
 Foundation; either version 2 of the License, or (at your option) any later
 version.

 This program is distributed in the hope that it will be useful, but WITHOUT
 ANY WARRANTY; without even the implied warranty of MERCHANTABILITY or FITNESS
 FOR A PARTICULAR PURPOSE. See the GNU General Public License for more details.

 You should have received a copy of the GNU General Public License along with
 this program; if not, write to the Free Software Foundation, Inc.,
 59 Temple Place, Suite 330, Boston, MA 02111-1307, USA
 */

// Some source about fuel/air ratio mixtures: http://www.apvgn.pt/documentacao/iangv_rep_part2.pdf

/**************************/
/* GASOLINE ENGINE CONFIG */
/**************************/
// [CONFIRMED] For gas car use 3355 (1/14.7/730*3600)*10000
#define GasConst 3355 
#define GasMafConst 107310 // 14.7*730*10

/************************/
/* LPG ENGINE CONFIG    */
/************************/
//LPG mass/volume is 520-580gr/ltr depending on propane/butane mix

// LPG/air ratio: 
// 15.8:1 if 50/50 propane/butate is used
// 15:1 if 100 propane is used
// 15.4 if 60/40 propane/butane is used
// experiments shows that something in middle should be used eg. 15.4:1 :)

// [TEST PROGRESS] For lpg(summer >20C) car use 4412 (1/15.4/540*3600)*10000
//#define GasConst 4329
//#define GasMafConst 83160  // 15.4*540*10 = 83160

/************************/
/* DIESEL ENGINE CONFIG */
/************************/
// [NOT TESTED] For diesel car use ???
//#define GasConst  2935 // (1/14.6/840*3600)*10000
//#define GasMafConst 122640 // 14.6*840*10

// Compilation modifiers:
// The following will cause the compiler to add or remove features from the OBDuino build this keeps the
// build size down, will not allow 'on the fly' changes. Some features are dependant on other features.

// Comment out to disable big numebers (4th and 5th sceeens)
#define use_BIG_font

// Comment for normal build
// Uncomment for a debug build
//#define DEBUG
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

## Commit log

2008-07-07 Modified the way to get PID
2008-07-08 correct bitmask for pid start to implement MIL check
    [obduino.pde]
2008-07-11 remove PSTR for LCD print
2008-07-11 correct some printf for long
    [obduino.pde]
2008-07-14 correct some printf with _P
    [obduino.pde]
2008-08-22 correct byte order of answer to PID
    [obduino.pde]
2008-09-22 perfect a few menu, pid up to 0x60, basic error checking
    [obduino.pde]
2008-10-05 correct avg fuel consumption
    [obduino.pde]
2008-10-06 correct avg trip fuel string if reset not moving
    [obduino.pde]
2008-10-08 optimize some functions and correct imperial display
    [obduino.pde]
2009-03-05 Added tracking of wasted gas. Modified iso_read_byte() to return a response if nothing is received so program doesn't get stuck. Fixed math for fuel consumption.
    [obduino.pde]
2009-03-05 forgot a line to reset fuel wasted
    [obduino.pde]
2009-03-13 Fixed Engine Breaking. Remove the fuel wasted display for ELM so it will fit. (ELM uses about 330 more bytes of space) Added some new PID's that will display stats for your current outing. rests ever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
    [obduino.pde]
2009-03-29 Will now clear current outing when the car starts running, not when the car engine shuts off
2009-04-16 Modified to compile under Arduino 0015
2009-04-30 Added ability to go beyond just 0xFx range of fake PID's Added new PID: Trip Time (0xEF). Made changes to make debugging easier. Added features back to ELM version since size is no longer a issue.
    [obduino32K.pde]
2009-05-06 Will now display 8 char description of PID not hex number. Will also flash up each description when screen is changed. The Description array probably should be moved into PROGMEM...
2009-06-10 Added Changes by Antony. Support for L line added, and other features and fixes.
    [obduino32K.pde]
2009-06-28 Minor display tweaks (gas price), correction in remaining distance calculation for gallons.
    [obduino32K.pde]
2009-09-01 Better handling of 19423 protocol (untested). Speed up menu operation with quicker button action.
2009-09-27 Correct four line LCD positioning. (Code correction provided by NickDigger via Ecomodder.com)
    [obduino32K.pde]
2010-08-30 Some LCD optimizations, formula for MAP, fix check_mil (untested)
    [obduino32K.pde]
2010-08-31 replace LCD routines by Arduino library calls
    [obduino32K.pde]
2010-08-31 fix old lcd_* commands in caralarm
    [obduino32K.pde]
2010-09-08 Hopefully correct some bug
    [obduino32K.pde]
2010-11-04 Made Changes as per Issue 10, "elm_write is wrong". serial.print changed to serial.write.
    [obduino32K.pde]
2011-03-29 AutoSave after 30min while driving (disabled by default) Config timeout (10s by default, last changes always accepted) (~100 bytes used) Battery voltage PID for ISO 9141 (was only for ELM) see get_ba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
    [obduino32K.pde]
2011-04-04 Driving and idling times for each trip (could be used for average speed and other in future) Max speed PID for each trip (max MAF, RPM, LOAD planned) ISO init first delay changes: 300ms, 600ms, 1200m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
2011-04-05 Bug fix for max speed display
    [obduino32K.pde]
2011-04-10 Single pid and data collection logging (see #define useSDCard section) Log buffering (one access to SD card takes ~170-200ms)
2011-07-18 Added buzzer functionality. Key response improvement.
    [obduino32K.pde]
2011-07-28 Buzzer fully disabled by default (no more compilation errors)
    [obduino32K.pde]
2012-03-26 Fixed compilation errors with ELM enabled.
    [obduino32K.pde]
2012-03-26 Background color switching

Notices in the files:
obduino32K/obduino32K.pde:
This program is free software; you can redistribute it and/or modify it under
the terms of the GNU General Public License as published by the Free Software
